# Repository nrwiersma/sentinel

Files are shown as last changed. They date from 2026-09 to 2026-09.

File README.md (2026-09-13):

<picture>
  <source media="(prefers-color-scheme: dark)" srcset="http://svg.wiersma.co.za/github/project.v2?title=sentinel&tag=presence%20detection&mode=dark">
  <source media="(prefers-color-scheme: light)" srcset="http://svg.wiersma.co.za/github/project.v2?title=sentinel&tag=presence%20detection">
  sentinel&tag=presence%20detection"
</picture>




`Sentinal` is a presence detection device that uses a mmWave to detect occupancy. It can be used to control lights, fans, 
or other devices based on occupancy. It also include a light sensor to detect ambient light levels as well as a temperature 
and humidity sensor.

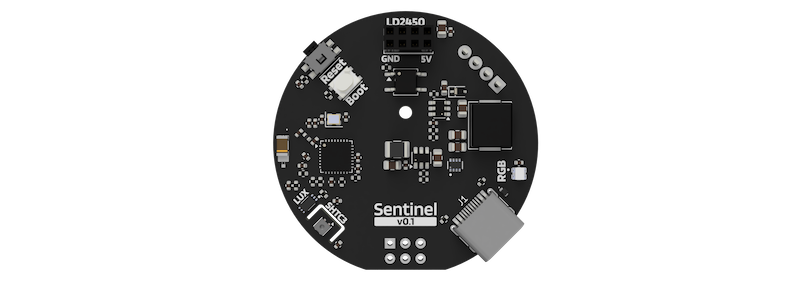
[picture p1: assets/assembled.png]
board image


## Key Features

* Presence detection using LD2450 mmWave radar
* Ambient light detection using BH1750 light sensor
* Temperature and humidity detection using SHTC3 sensor
* RGB LED for status indication
* Native alarm integration

## Firmware

ESPHome firmware is available for the device. See the releases for the latest version. The firmware can be flashed 
using the [ESPHome Web installer](https://web.esphome.io).

## Hardware

The hardware is based on the ESP32-C3 module and the LD2450 mmWave radar module. The device is designed to be low power 
and can be powered using a 12v power supply, which is fairly common in home alarm systems.

See the [Schematic](/blob/main/hardware/schematic.pdf) for more details on the hardware design.

### BOM

See the [Interactive BOM](https://htmlpreview.github.io/?https://github.com/nrwiersma/sentinel/blob/main/bom/ibom.html) [(provided by InteractiveHtmlBom)
](https://github.com/openscopeproject/InteractiveHtmlBom).

### Update LD2450 Firmware

* Download the HLKRadarTool on your phone
* Connect to the LD2450 module via Bluetooth
* Update the firmware to version 2.04.23101915 or later

> [!WARNING]
> If upgrading the firmware version to 2.14 or later, you need to set the baud rate back to 256000 in the HLKRadarTool 
> app. This version change seems to reset the baud rate, and Sentinel will no longer be able to communicate with the LD2450 module.

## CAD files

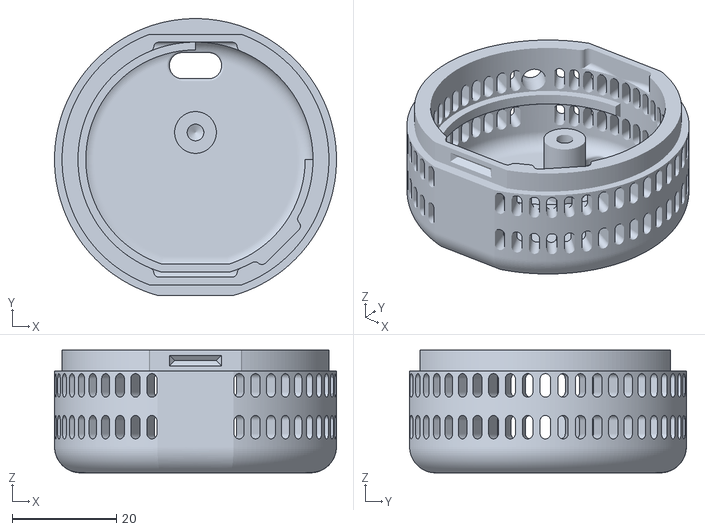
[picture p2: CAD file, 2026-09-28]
models/Base.stl
54.0 x 53.0 x 23.5

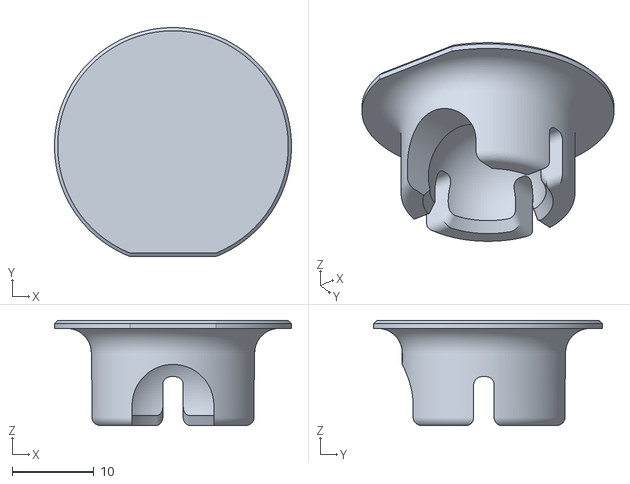
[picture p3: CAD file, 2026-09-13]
models/Ball Socket.stl
29.0 x 28.0 x 12.9

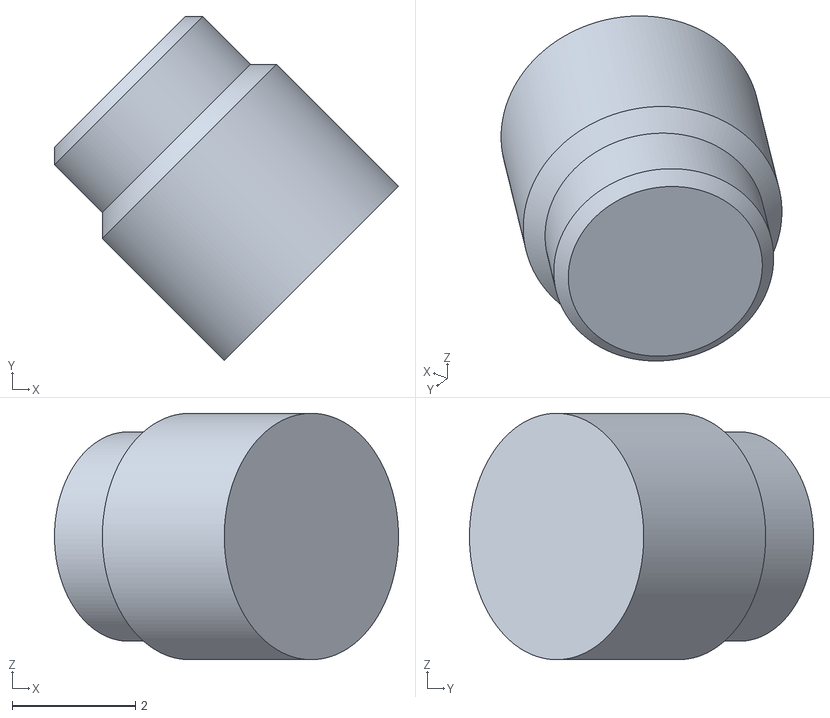
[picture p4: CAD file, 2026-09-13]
models/Button.stl
5.59 x 5.59 x 4.00

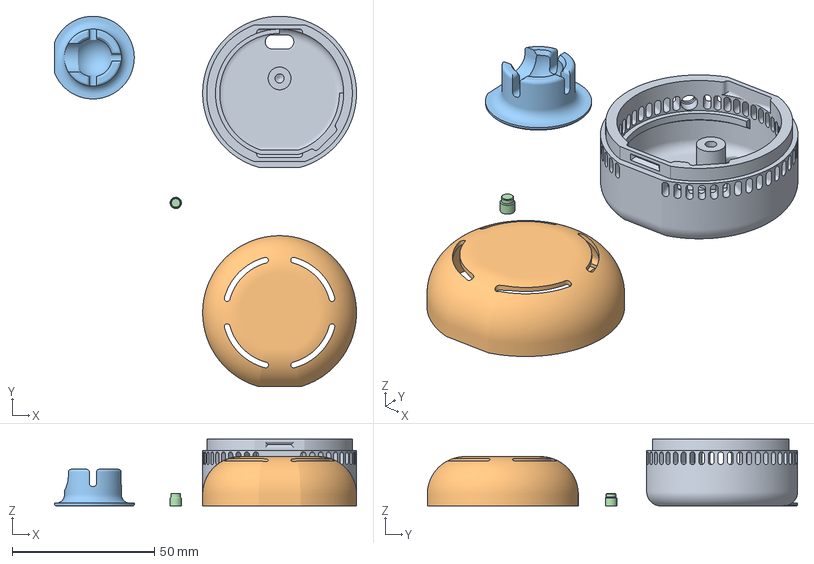
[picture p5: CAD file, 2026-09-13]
models/Sentinel.3mf
106.0 x 130.0 x 23.5 mm
Base.stl
Lid.stl
Ball Socket.stl
Button.stl

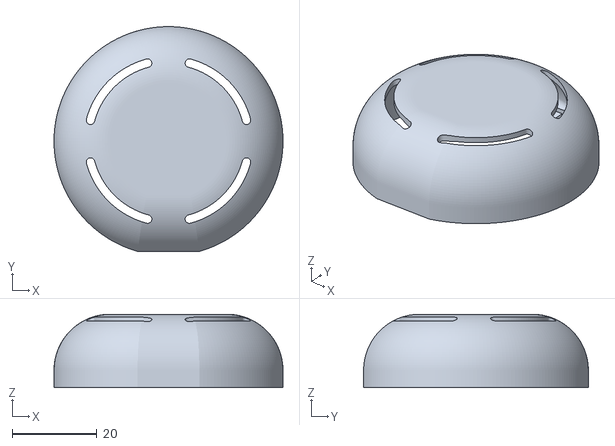
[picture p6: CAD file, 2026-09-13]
models/Lid.stl
54.0 x 53.0 x 17.3

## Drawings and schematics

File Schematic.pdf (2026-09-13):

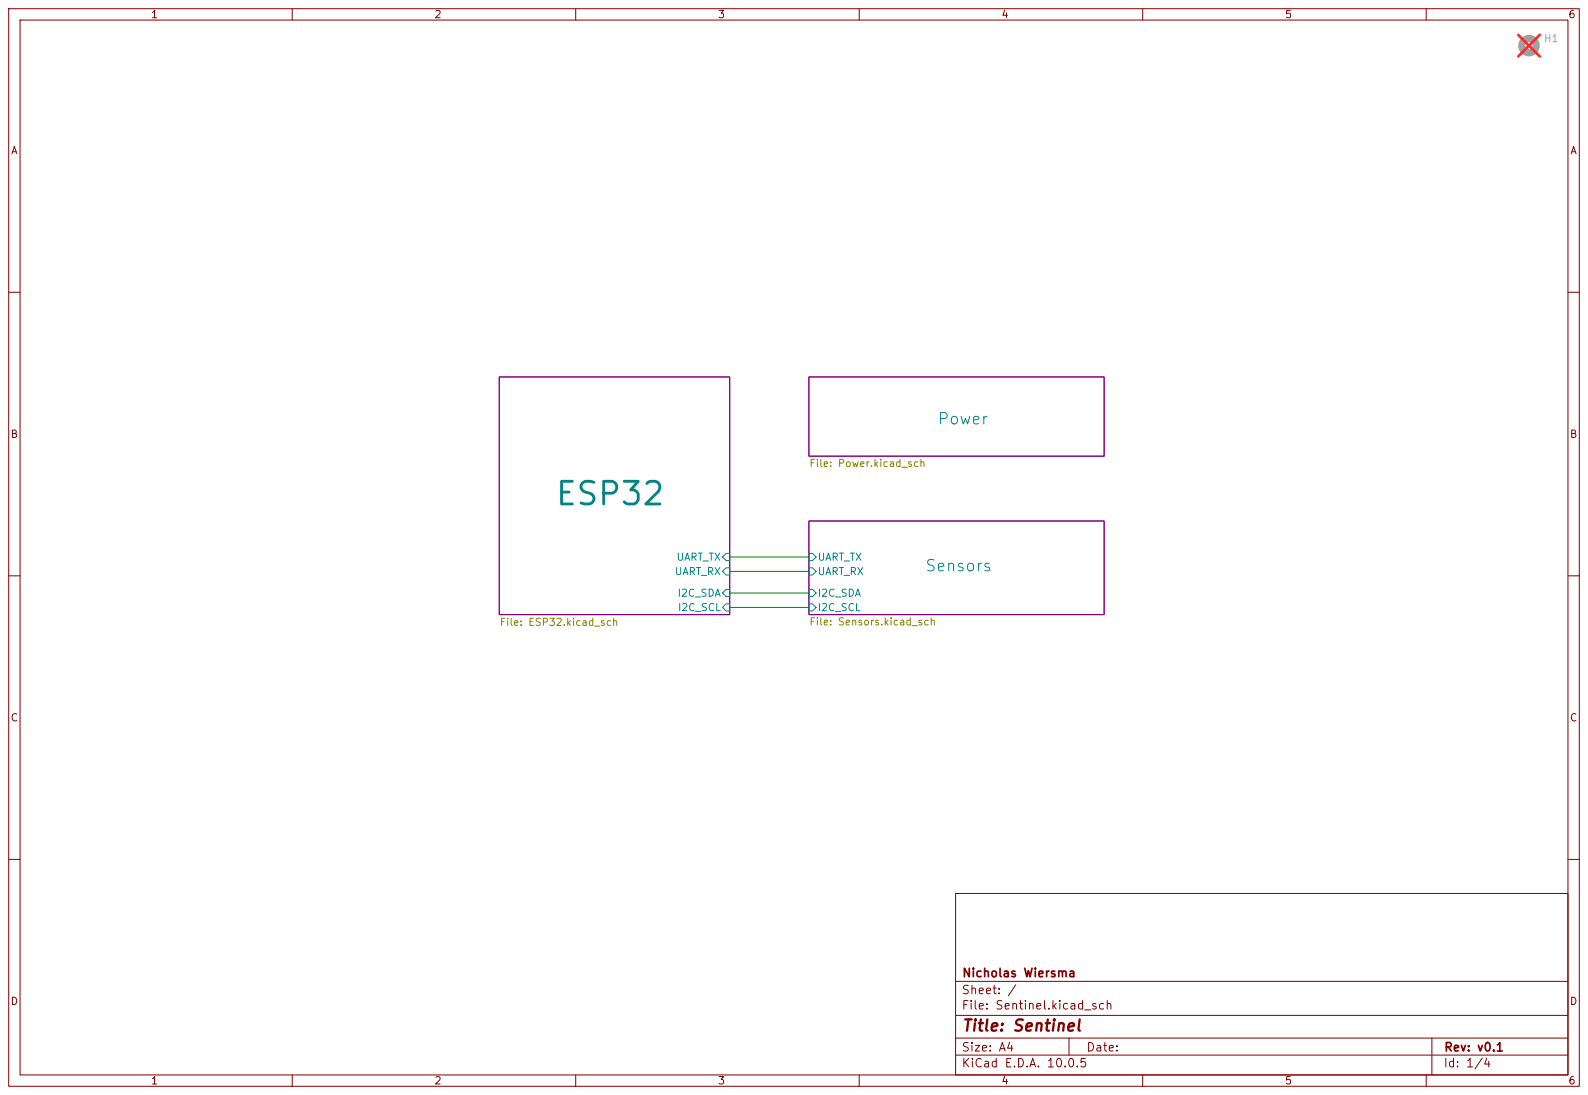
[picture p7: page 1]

Size: A4 | Rev: v0.1
KiCad E.D.A. 10.0.5 | Id: 1/4

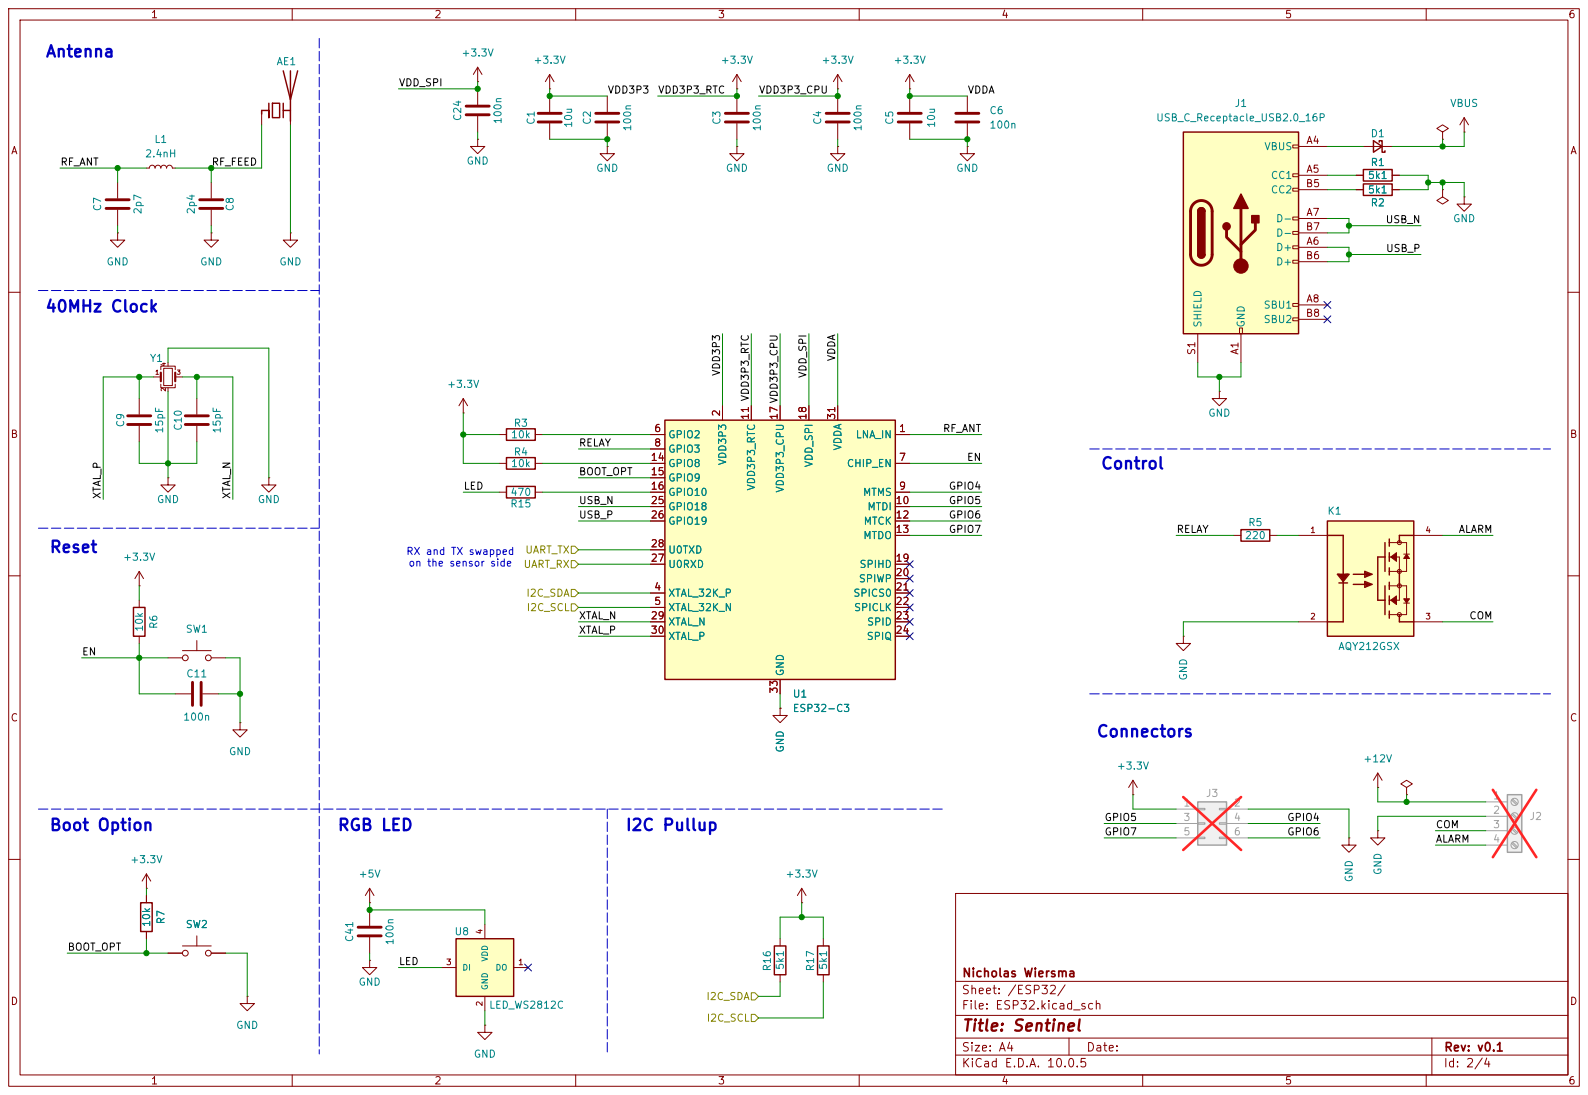
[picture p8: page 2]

on the sensor side 40MHz Clock

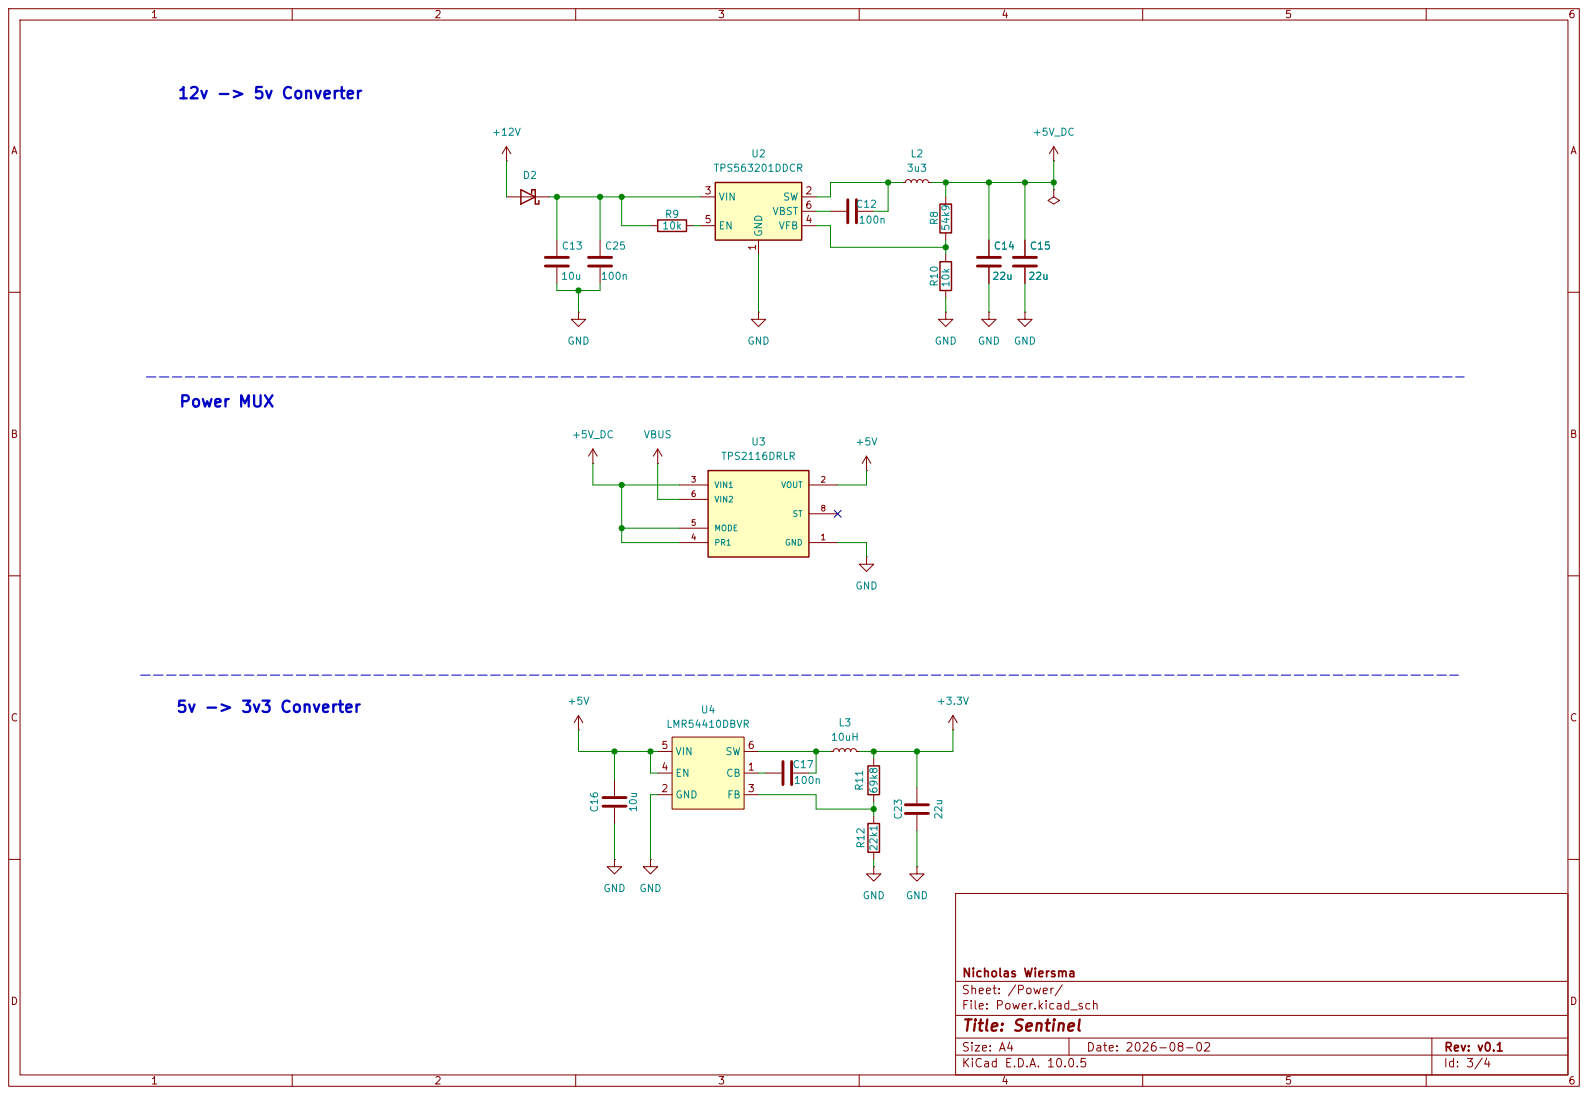
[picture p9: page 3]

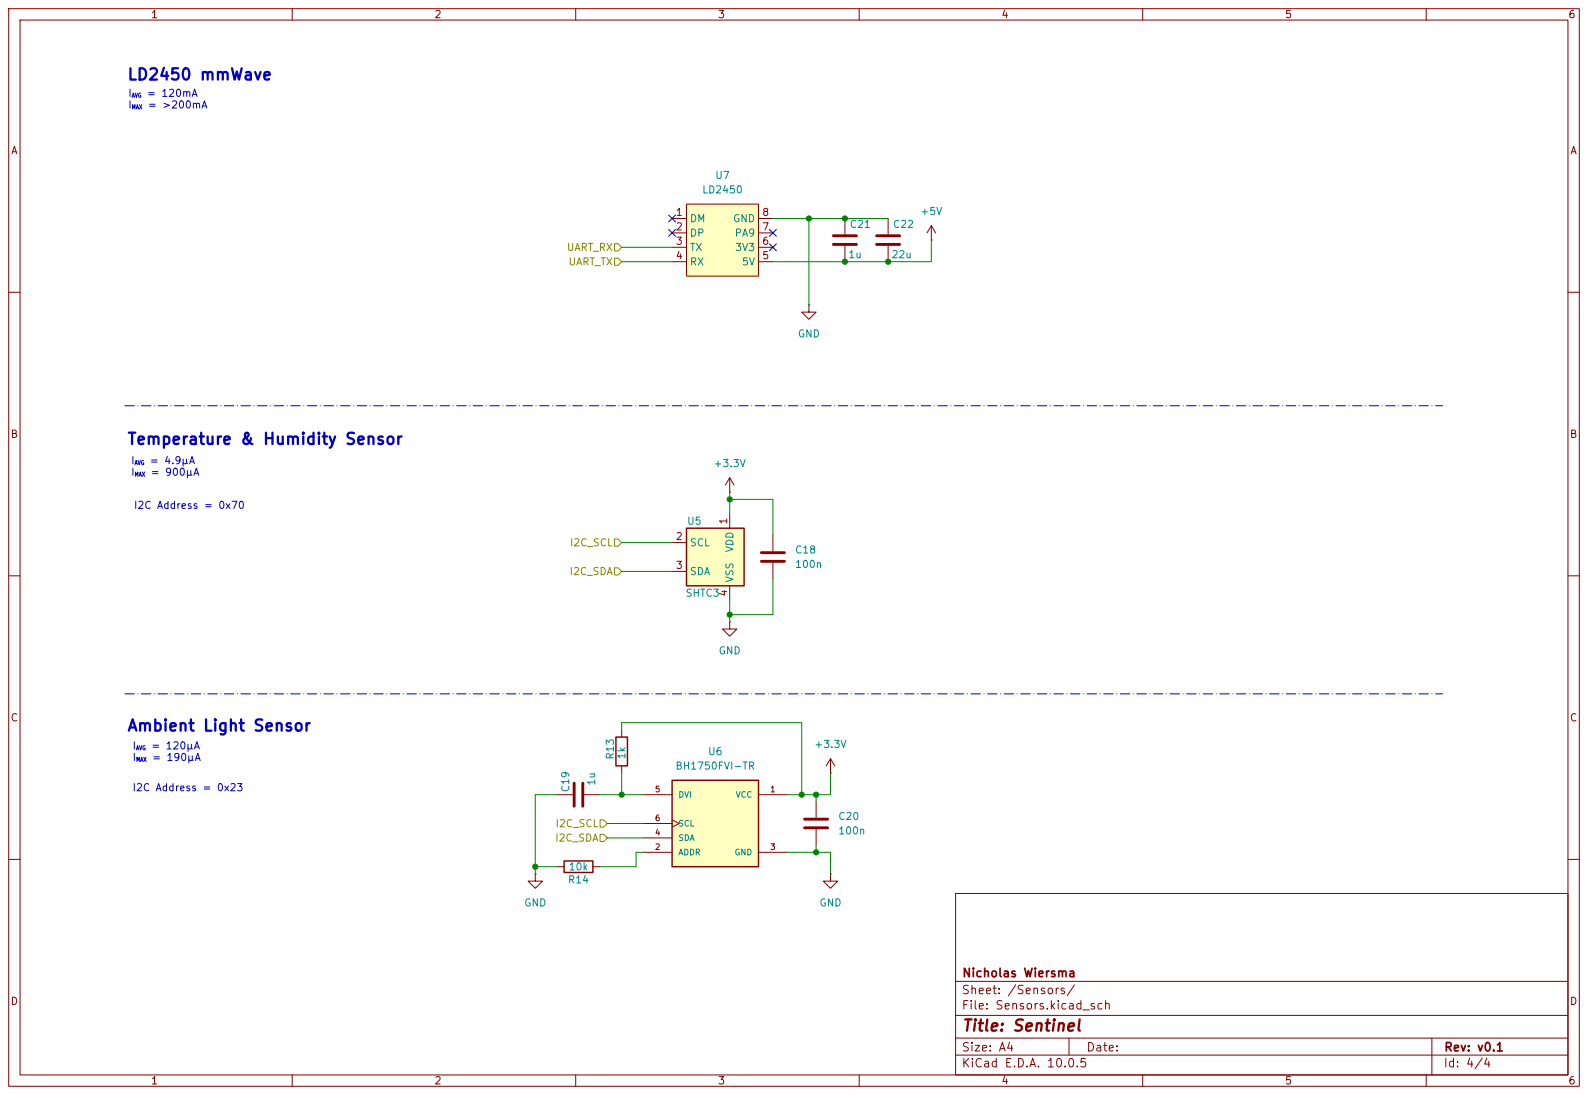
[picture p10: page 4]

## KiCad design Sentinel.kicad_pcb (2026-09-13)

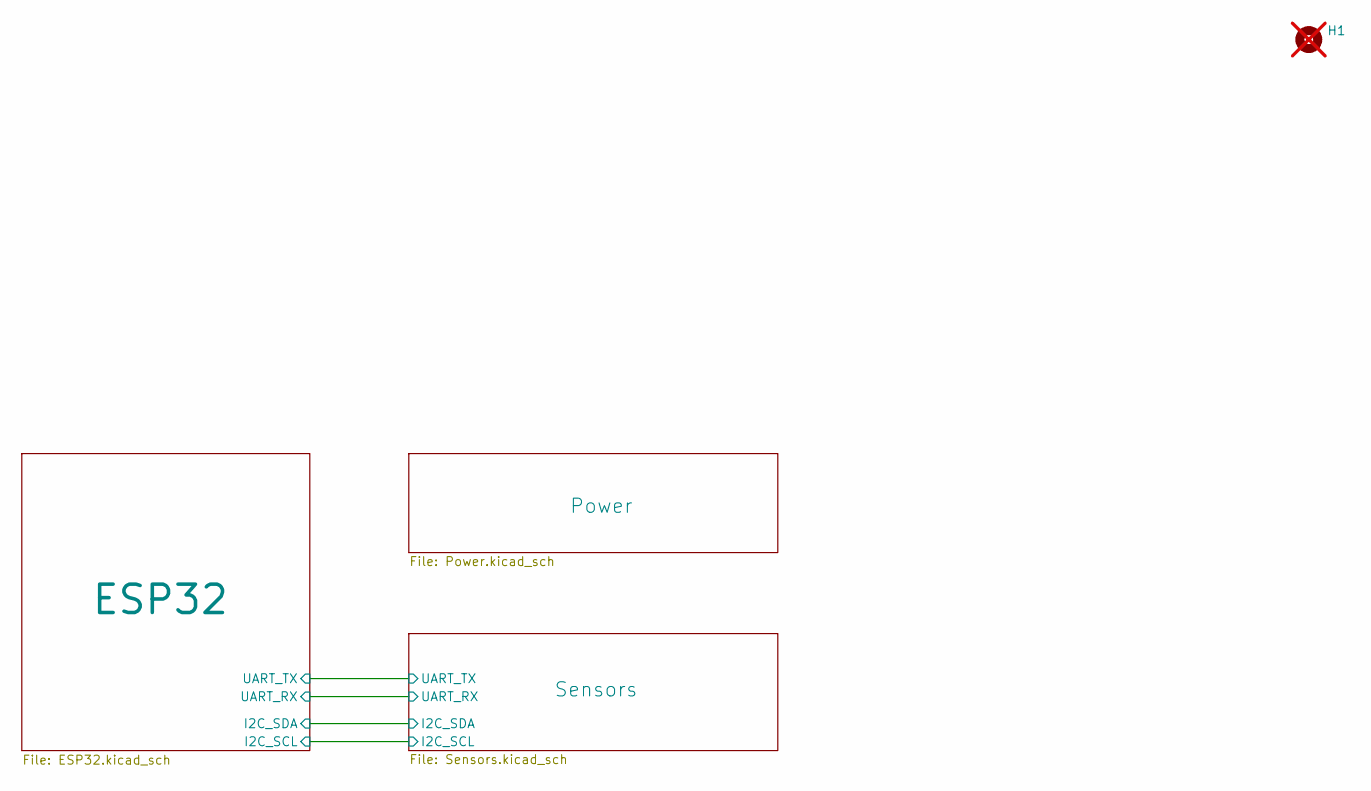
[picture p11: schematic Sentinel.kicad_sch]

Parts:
H1: MountingHole; MountingHole_2.2mm_M2; not fitted

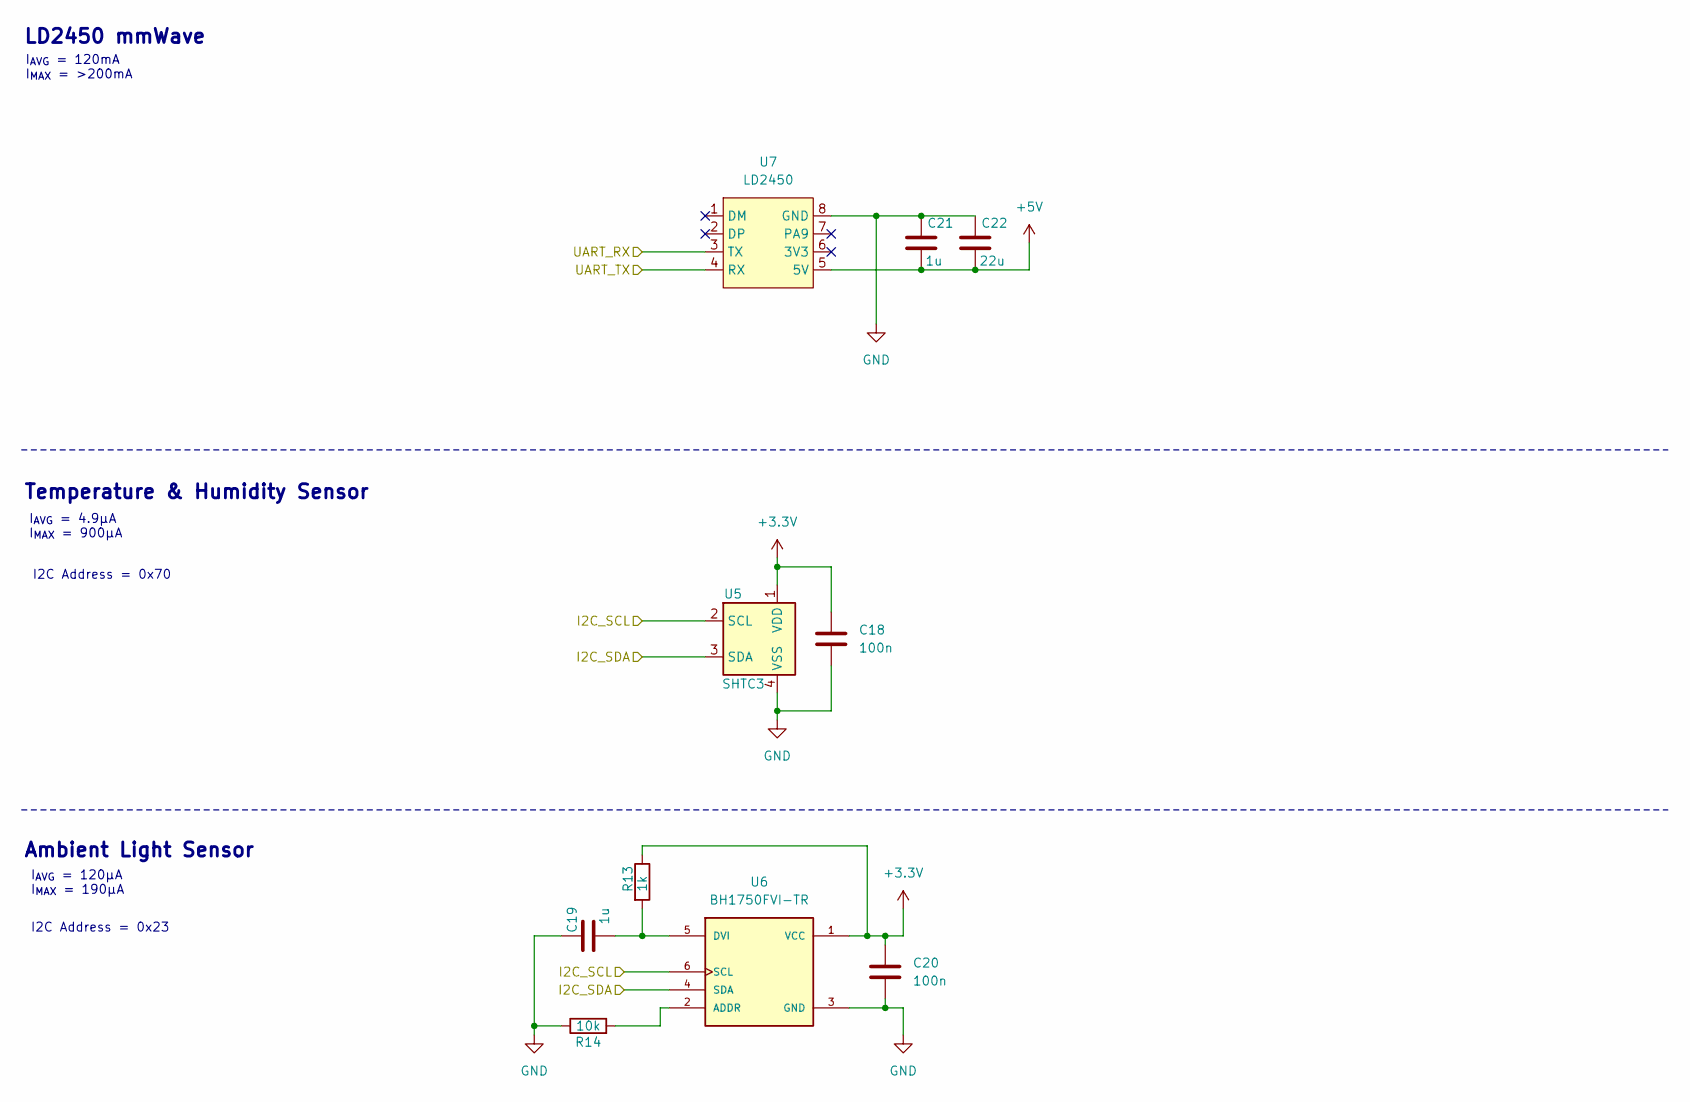
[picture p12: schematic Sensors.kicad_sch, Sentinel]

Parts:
C18, C20: 100n; C_0402_1005Metric; MPN CL05B104KO5NNNC; JLCPCB Part # C1525
C19, C21: 1u; C_0402_1005Metric; MPN CL05A105KP5NNNC; JLCPCB Part # C14445
C22: 22u; C_0805_2012Metric; MPN CL21A226KPCLRNC; JLCPCB Part # C318688
R13: 1k; R_0402_1005Metric; MPN RK73H1ETTP1001F; JLCPCB Part # C131360
R14: 10k; R_0402_1005Metric; MPN RC0402FR-0710KL; JLCPCB Part # C60490
U5: SHTC3; SHTC3-TR; MPN SHTC3-TR-10KS; JLCPCB Part # C2880044
U6: BH1750FVI-TR; MPN BH1750FVI-TR; JLCPCB Part # C78960
U7: LD2450; MPN 2005FV-2x4P; JLCPCB Part # C18723066

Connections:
+3.3V: C18.1, C20.1, R13.1, U5.1 (VDD), U6.1 (VCC); also elsewhere on the board
+5V: C21.2, C22.2, U7.5 (5V); also elsewhere on the board
/ESP32/I2C_SCL: U5.2 (SCL), U6.6 (SCL); also elsewhere on the board
/ESP32/I2C_SDA: U5.3 (SDA), U6.4 (SDA); also elsewhere on the board
/ESP32/UART_RX: U7.3 (TX); also elsewhere on the board
/ESP32/UART_TX: U7.4 (RX); also elsewhere on the board
GND: C18.2, C19.1, C20.2, C21.1, C22.1, R14.1, U5.4 (VSS), U6.3 (GND), U7.8 (GND); also elsewhere on the board
unnamed: R14.2, U6.2 (ADDR)
unnamed: C19.2, R13.2, U6.5 (DVI)

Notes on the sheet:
I2C Address = 0x70
I_{AVG} = 120μA I_{MAX} = 190μA
I_{AVG} = 120mA I_{MAX} = >200mA
I_{AVG} = 4.9μA I_{MAX} = 900μA
Ambient Light Sensor
LD2450 mmWave
Temperature & Humidity Sensor
I2C Address = 0x23

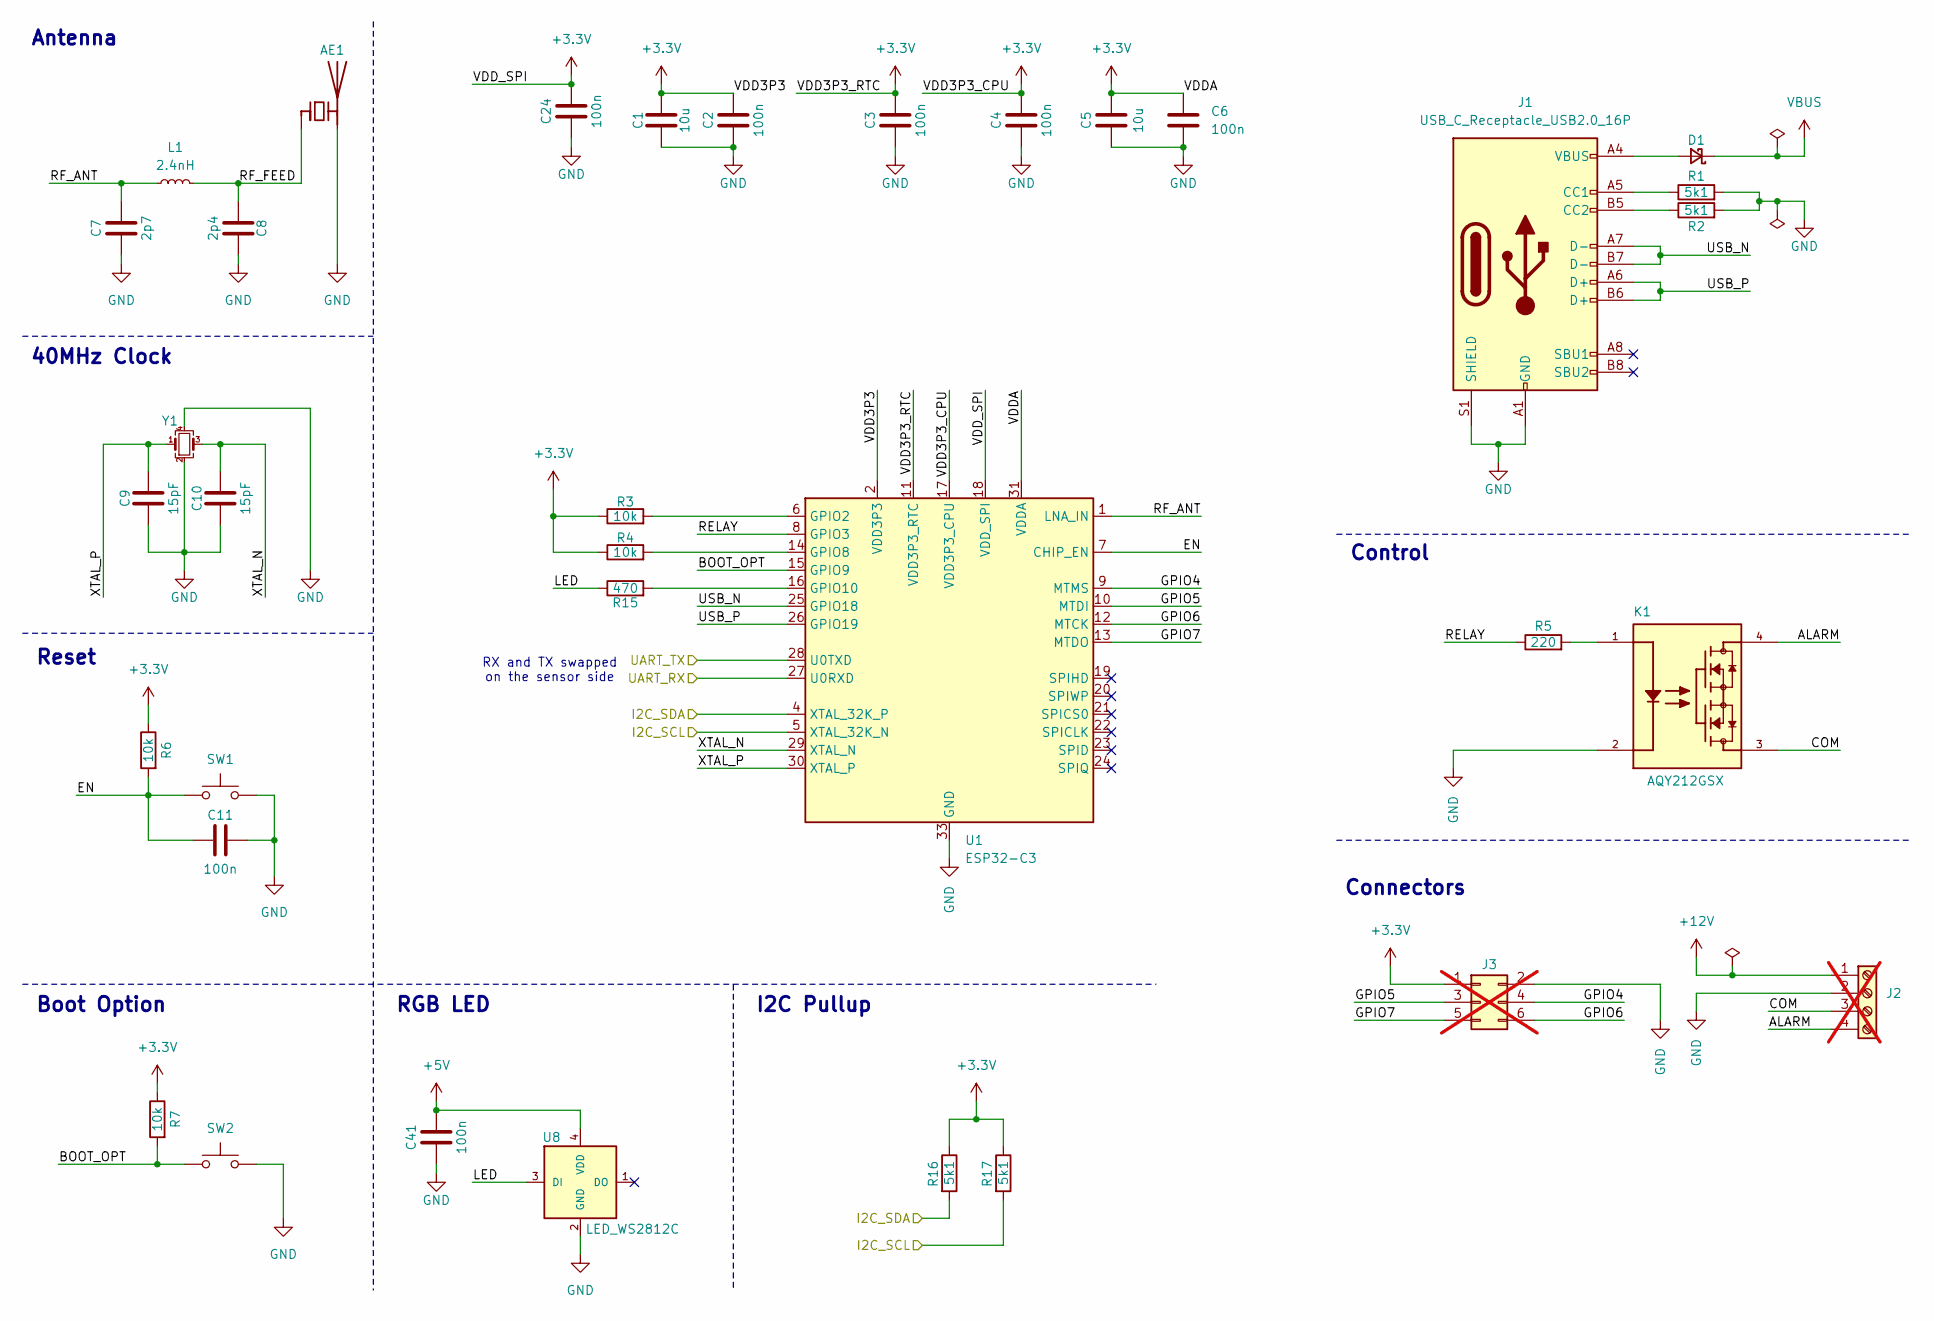
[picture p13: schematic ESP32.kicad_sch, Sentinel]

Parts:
AE1: Ant_RFECA3216060A1T_1206; Ant_RFECA3216060A1T; MPN RFECA3216060A1T; JLCPCB Part # C127620
C1, C5: 10u; C_0402_1005Metric; MPN CL05A106MP5NUNC; JLCPCB Part # C315248
C2, C3, C4, C6, C11, C24, C41: 100n; C_0402_1005Metric; MPN CL05B104KO5NNNC; JLCPCB Part # C1525
C7: 2p7; C_0402_1005Metric; MPN CL05C2R7BB5NNNC; JLCPCB Part # C159805
C8: 2p4; C_0402_1005Metric; MPN CL05C2R4CB5NNNC; JLCPCB Part # C318575
C9, C10: 15pF; C_0402_1005Metric; MPN CL05C150JB5NNNC; JLCPCB Part # C86285
D1: D_Schottky_Small; D_0402_1005Metric; MPN CDBQC0130L-HF; JLCPCB Part # C2886012
J1: USB_C_Receptacle_USB2.0_16P; USB_C_Receptacle_HRO_TYPE-C-31-M-12; MPN TYPE-C-31-M-12; JLCPCB Part # C165948
J2: Screw_Terminal_01x04; TerminalBlock_Phoenix_MPT-0,5-4-2.54_1x04_P2.54mm_Horizontal; not fitted
J3: Conn_02x03_Odd_Even; PinHeader_2x03_P2.54mm_Vertical; not fitted
K1: AQY212GSX; SSR_SUPSiC_GAQY212GSX; MPN GAQY212GSX; JLCPCB Part # C19271988
L1: 2.4nH; L_0402_1005Metric; MPN MLG1005S2N4BT000; JLCPCB Part # C275281
R1, R2, R16, R17: 5k1; R_0402_1005Metric; MPN RC0402FR-075K1L; JLCPCB Part # C105872
R3, R4, R6, R7: 10k; R_0402_1005Metric; MPN RC0402FR-0710KL; JLCPCB Part # C60490
R5: 220; R_0402_1005Metric; MPN RC0402FR-07220RL; JLCPCB Part # C112291
R15: 470; R_0402_1005Metric; MPN RC0402FR-7W470RL; JLCPCB Part # C606172
SW1: SW_Push; SW_Panasonic_EVQPUC; MPN EVQPUC02K; JLCPCB Part # C79174
SW2: SW_Push; SW_PTS815SJM250SMTRLFS; MPN SKRPACE010; JLCPCB Part # C139797
U1: ESP32-C3; QFN-32-1EP; MPN ESP32-C3FH4; JLCPCB Part # C2858491
U8: LED_WS2812C; LED_WS2812C-2020; MPN WS2812C-2020; JLCPCB Part # C2976072
Y1: ECS-400-10-37B2-CKM-TR; Oscillator_ECS_400-10-37B2-CKM-TR; MPN ECS-400-10-37B2-CKM-TR; JLCPCB Part # C5371760

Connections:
+3.3V: C1.1, C2.1, C3.1, C4.1, C5.1, C6.1, C24.1, J3.1, R3.1, R4.1, R6.1, R7.1, R16.1, R17.1, U1.2 (VDD3P3), U1.3 (VDD3P3), U1.11 (VDD3P3_RTC), U1.17 (VDD3P3_CPU), U1.18 (VDD_SPI), U1.31 (VDDA), U1.32 (VDDA); also elsewhere on the board
+5V: C41.1, U8.4 (VDD); also elsewhere on the board
+12V: J2.1; also elsewhere on the board
/ESP32/ALARM: J2.4, K1.4
/ESP32/BOOT_OPT: R7.2, SW2.2, U1.15 (GPIO9)
/ESP32/COM: J2.3, K1.3
/ESP32/EN: C11.1, R6.2, SW1.2, U1.7 (CHIP_EN)
/ESP32/GPIO4: J3.4, U1.9 (MTMS)
/ESP32/GPIO5: J3.3, U1.10 (MTDI)
/ESP32/GPIO6: J3.6, U1.12 (MTCK)
/ESP32/GPIO7: J3.5, U1.13 (MTDO)
/ESP32/I2C_SCL: R17.2, U1.5 (XTAL_32K_N); also elsewhere on the board
/ESP32/I2C_SDA: R16.2, U1.4 (XTAL_32K_P); also elsewhere on the board
/ESP32/LED: R15.1, U8.3 (DI)
/ESP32/RELAY: R5.1, U1.8 (GPIO3)
/ESP32/RF_ANT: C7.1, L1.1, U1.1 (LNA_IN)
/ESP32/RF_FEED: AE1.1 (FEED), C8.2, L1.2
/ESP32/UART_RX: U1.27 (U0RXD); also elsewhere on the board
/ESP32/UART_TX: U1.28 (U0TXD); also elsewhere on the board
/ESP32/USB_N: J1.A7 (D-), J1.B7 (D-), U1.25 (GPIO18)
/ESP32/USB_P: J1.A6 (D+), J1.B6 (D+), U1.26 (GPIO19)
/ESP32/XTAL_N: C10.1, U1.29 (XTAL_N), Y1.3
/ESP32/XTAL_P: C9.1, U1.30 (XTAL_P), Y1.1
GND: AE1.2 (PCB_Trace), C1.2, C2.2, C3.2, C4.2, C5.2, C6.2, C7.2, C8.1, C9.2, C10.2, C11.2, C24.2, C41.2, J1.A1 (GND), J1.A12 (GND), J1.B1 (GND), J1.B12 (GND), J1.S1 (SHIELD), J2.2, J3.2, K1.2, R1.2, R2.2, SW1.1, SW2.1, U1.33 (GND), U8.2 (GND), Y1.2, Y1.4; also elsewhere on the board
unnamed: D1.2 (A), J1.A4 (VBUS), J1.A9 (VBUS), J1.B4 (VBUS), J1.B9 (VBUS)
unnamed: J1.A5 (CC1), R1.1
unnamed: J1.B5 (CC2), R2.1
unnamed: K1.1, R5.2
unnamed: R3.2, U1.6 (GPIO2)
unnamed: R4.2, U1.14 (GPIO8)
unnamed: R15.2, U1.16 (GPIO10)
VBUS: D1.1 (K); also elsewhere on the board

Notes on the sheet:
Boot Option
RGB LED
Antenna
Connectors
I2C Pullup
RX and TX swapped on the sensor side
40MHz Clock
Control
Reset

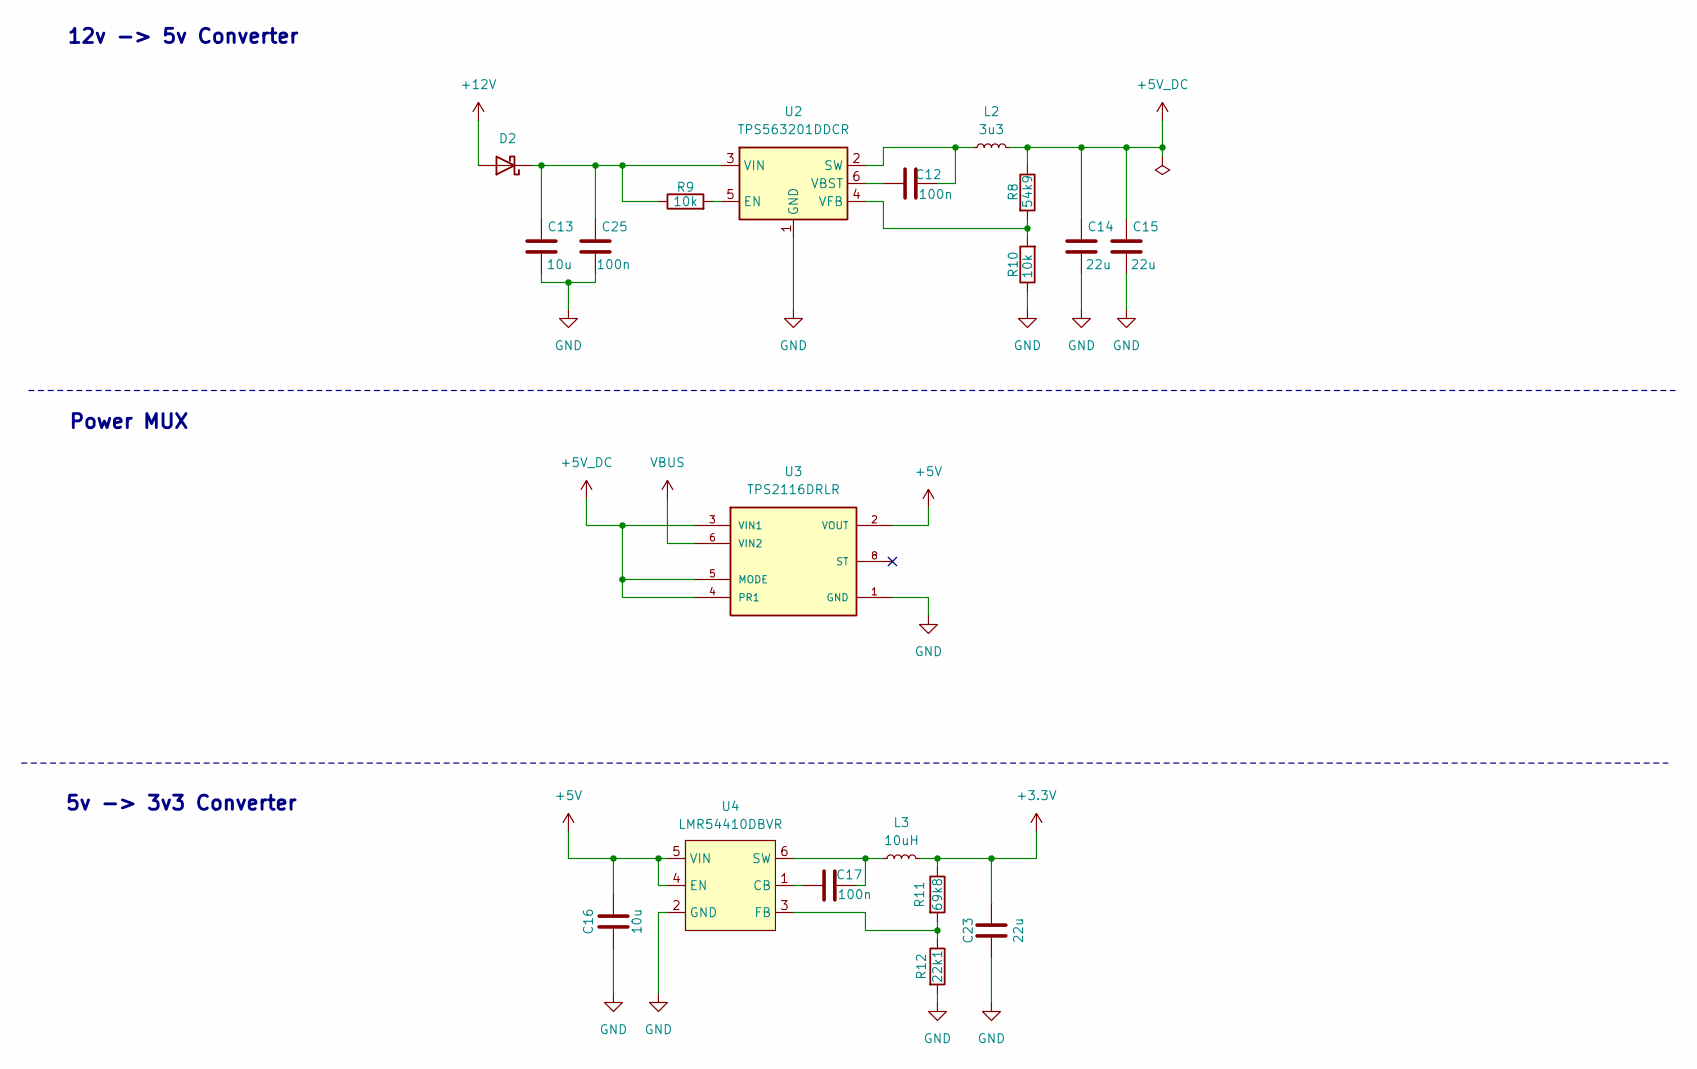
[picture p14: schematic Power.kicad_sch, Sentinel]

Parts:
C12, C17: 100n; C_0402_1005Metric; MPN CL05B104KO5NNNC; JLCPCB Part # C1525
C13, C16: 10u; C_0805_2012Metric; MPN CL21A106KAYNNNE; JLCPCB Part # C15850
C14, C15, C23: 22u; C_0805_2012Metric; MPN CL21A226KPCLRNC; JLCPCB Part # C318688
C25: 100n; C_0603_1608Metric; MPN CL10B104KA8NNNC; JLCPCB Part # C1590
D2: 1N5819WS; D_SOD-323; MPN 1N5819WS; JLCPCB Part # C191023
L2: 3u3; L_Chilisin_BMRx00060630; MPN MHCI06030-3R3M-S8; JLCPCB Part # C285713
L3: 10uH; L_1210_3225Metric; MPN TMS322512ALM-100MTAA; JLCPCB Part # C20244098
R8: 54k9; R_0402_1005Metric; MPN AC0402FR-0754K9L; JLCPCB Part # C227137
R9, R10: 10k; R_0402_1005Metric; MPN RC0402FR-0710KL; JLCPCB Part # C60490
R11: 69k8; R_0402_1005Metric; MPN AC0402FR-0769K8L; JLCPCB Part # C227195
R12: 22k1; R_0402_1005Metric; MPN RC0402FR-0722K1L; JLCPCB Part # C163478
U2: TPS563201DDCR; SOT-23-6; MPN TPS563201DDCR; JLCPCB Part # C116592
U3: TPS2116DRLR; SOTFL50P160X60-8N; MPN TPS2116DRLR; JLCPCB Part # C3235557
U4: LMR54410DBVR; SOT-23-6; MPN LMR54410DBVR; JLCPCB Part # C3200265

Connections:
+3.3V: C23.2, L3.2, R11.1; also elsewhere on the board
+5V: C16.2, U3.2 (VOUT), U3.7 (VOUT), U4.4 (EN), U4.5 (VIN); also elsewhere on the board
+5V_DC: C14.1, C15.1, L2.2, R8.1, U3.3 (VIN1), U3.4 (PR1), U3.5 (MODE)
+12V: D2.2 (A); also elsewhere on the board
GND: C13.2, C14.2, C15.2, C16.1, C23.1, C25.2, R10.1, R12.2, U2.1 (GND), U3.1 (GND), U4.2 (GND); also elsewhere on the board
unnamed: C13.1, C25.1, D2.1 (K), R9.1, U2.3 (VIN)
unnamed: R9.2, U2.5 (EN)
unnamed: C12.2, L2.1, U2.2 (SW)
unnamed: C12.1, U2.6 (VBST)
unnamed: R8.2, R10.2, U2.4 (VFB)
unnamed: C17.1, U4.1 (CB)
unnamed: R11.2, R12.1, U4.3 (FB)
unnamed: C17.2, L3.1, U4.6 (SW)
VBUS: U3.6 (VIN2); also elsewhere on the board

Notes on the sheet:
5v -> 3v3 Converter
Power MUX
12v -> 5v Converter

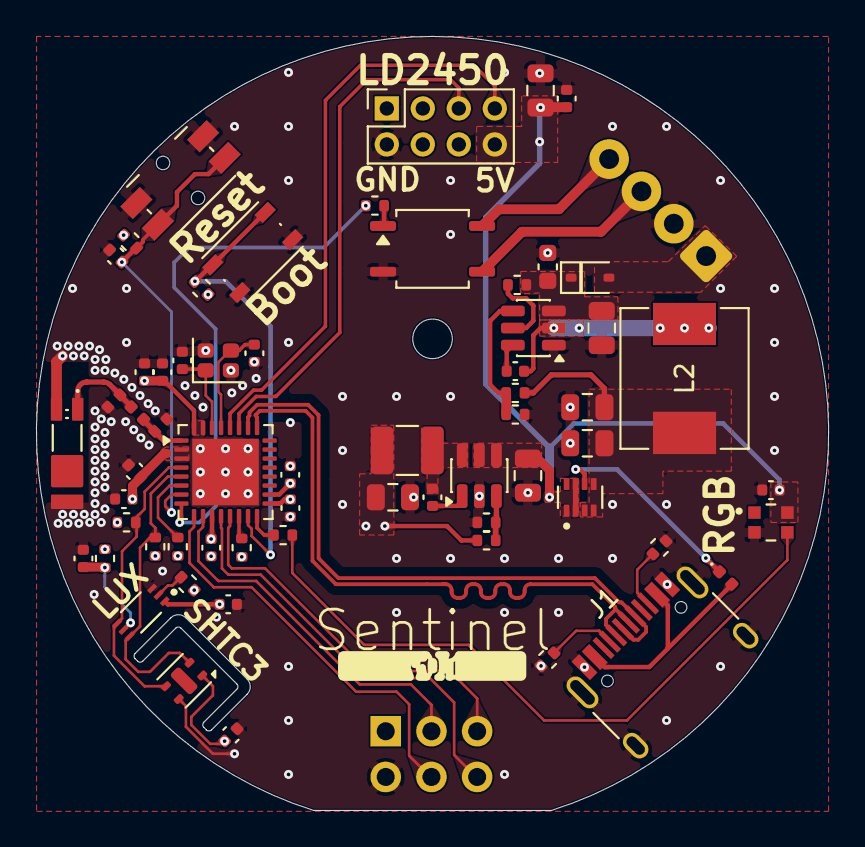
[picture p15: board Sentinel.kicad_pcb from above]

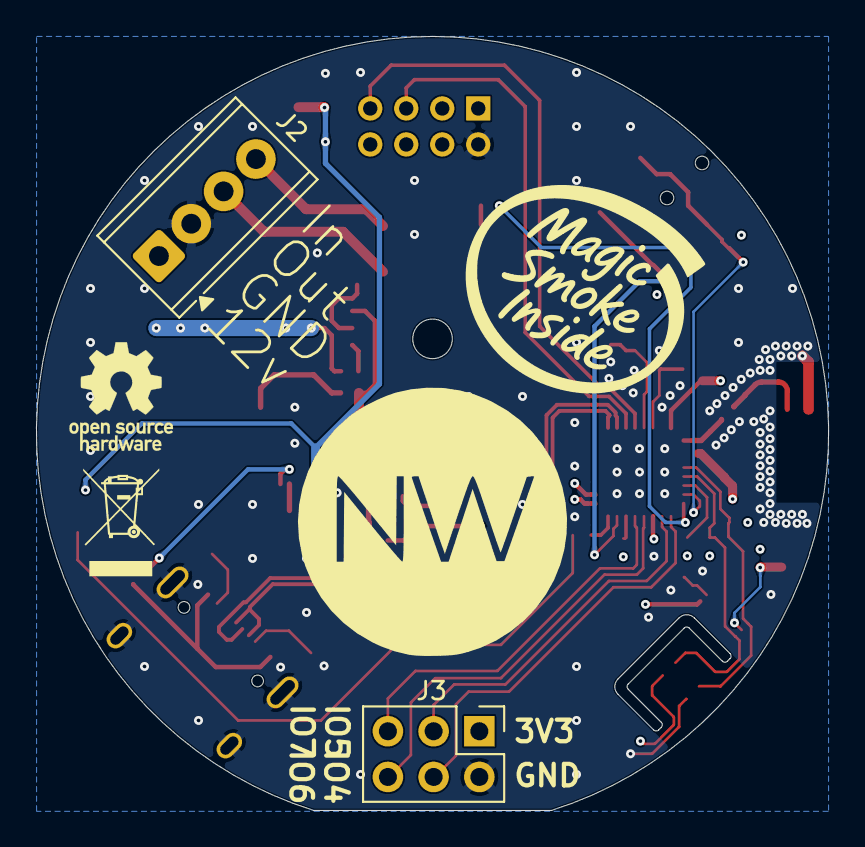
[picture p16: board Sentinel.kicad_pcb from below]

Board: 4 copper layers, 44.0 x 43.0 mm, 65 parts (2 on the bottom side), 43 nets.

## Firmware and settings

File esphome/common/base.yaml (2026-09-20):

esphome:
  project:
    name: nrwiersma.Sentinel
    version: "0.1.0"
  on_boot:
    - priority: 375
      then:
        - delay: 200ms
        - script.execute: update_relay_state
        # Start loading animation and keep it until API connects
        - if:
            condition:
              lambda: 'return id(status_led_select).current_option() == "Enabled";'
            then:
              - light.turn_on:
                  id: led_rgb
                  brightness: 30%
                  red: 0%
                  green: 60%
                  blue: 100%
                  white: 0%
                  effect: "Network Connecting"

logger:
  level: ${log_level}

api:
  id: api_id
  on_client_connected:
    then:
      # Wait until client has subscribed
      - wait_until:
          condition:
            api.connected:
              state_subscription_only: true
          timeout: 3s
      - if:
          condition:
            lambda: 'return id(status_led_select).current_option() == "Enabled" && id(led_mode_select).current_option() != "Manual Control";'
          then:
            # Stop any effects first
            - light.turn_on:
                id: led_rgb
                effect: none
            # Smooth celebration sequence with flowing colors
            - light.turn_on:
                id: led_rgb
                brightness: 60%
                red: 0%
                green: 100%
                blue: 100%
                white: 0%
                transition_length: 400ms
            - delay: 400ms
            - light.turn_on:
                id: led_rgb
                brightness: 65%
                red: 0%
                green: 70%
                blue: 100%
                white: 0%
                transition_length: 350ms
            - delay: 350ms
            - light.turn_on:
                id: led_rgb
                brightness: 70%
                red: 50%
                green: 0%
                blue: 100%
                white: 0%
                transition_length: 350ms
            - delay: 350ms
            - light.turn_on:
                id: led_rgb
                brightness: 65%
                red: 100%
                green: 100%
                blue: 100%
                white: 0%
                transition_length: 400ms
            - delay: 500ms
      # Always restore to current mode, even if Manual Control
      - script.execute: control_leds

  on_client_disconnected:
    then:
      - script.execute: control_leds

http_request:
  verify_ssl: false

ota:
  - platform: esphome
  - platform: http_request
    id: ota_http_request

sensor:
  - platform: shtcx
    id: "shtc3_sensor"
    i2c_id: bus_a
    address: 0x70
    update_interval: 30s
    temperature:
      name: Temperature
      id: temperature_sensor
      filters:
        - lambda: "return x + id(env_temperature_offset).state;"
    humidity:
      name: Humidity
      id: humidity_sensor
      filters:
        - lambda: "return x + id(env_humidity_offset).state;"

  - platform: bh1750
    name: Illuminance
    id: illuminance_sensor
    i2c_id: bus_a
    address: 0x23
    update_interval: 2s
    filters:
      - lambda: "return x + id(env_illuminance_offset).state;"
      - or:
          - throttle: 30s
          - delta: 2
      - clamp:
          min_value: 0

i2c:
  - id: bus_a
    scl: GPIO1
    sda: GPIO0
    scan: true

binary_sensor:
  - platform: template
    name: Occupancy
    id: occupancy
    device_class: occupancy
    filters:
      - delayed_off: !lambda 'return id(occupancy_off_delay).state * 1000.0;'
    lambda: |-
      return id(ld2450_occupancy).state;
    on_state:
      then:
        - lambda: |-
            auto mode = id(system_alarm_mode).current_option();
            if (mode == "Presence") {
              bool activate = id(occupancy).state;
              bool desired = (id(relay_contact_mode).current_option() == "Normally Open (NO)") ? activate : !activate;
              if (desired) {
                id(system_alarm_relay).turn_on();
              } else {
                id(system_alarm_relay).turn_off();
              }
            }
        - if:
            condition:
              lambda: |-
                return id(led_mode_select).current_option() == "Presence";
            then:
              - script.execute: control_leds
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

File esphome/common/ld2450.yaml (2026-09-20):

uart:
  id: uart_bus
  tx_pin: GPIO21
  rx_pin: GPIO20
  baud_rate: 256000
  parity: NONE
  stop_bits: 1

ld2450:
  id: ld2450_radar
  uart_id: uart_bus
  on_data:
    - lambda: |-
        struct Poly { float vx[20]; float vy[20]; int count; };
        static Poly zones[4], exclusions[2];

        if (!id(poly_initialized)) {
          auto parse = [](const std::string &text, Poly &poly) {
            poly.count = 0;
            size_t pos = 0;
            while (pos < text.length() && poly.count < 20) {
              int x, y, n;
              if (sscanf(text.c_str() + pos, "%d:%d%n", &x, &y, &n) == 2) {
                poly.vx[poly.count] = (float)x;
                poly.vy[poly.count] = (float)y;
                poly.count++;
                pos += n;
                if (pos < text.length() && text[pos] == ';') pos++;
              } else {
                break;
              }
            }
          };
          parse(id(poly_zone_1).state, zones[0]);
          parse(id(poly_zone_2).state, zones[1]);
          parse(id(poly_zone_3).state, zones[2]);
          parse(id(poly_zone_4).state, zones[3]);
          parse(id(poly_exclusion_1).state, exclusions[0]);
          parse(id(poly_exclusion_2).state, exclusions[1]);
          id(poly_initialized) = true;
        }

        auto in_poly = [](float px, float py, const Poly &poly) -> bool {
          if (poly.count < 3) return false;
          bool inside = false;
          for (int i = 0, j = poly.count - 1; i < poly.count; j = i++) {
            float xi = poly.vx[i], yi = poly.vy[i];
            float xj = poly.vx[j], yj = poly.vy[j];
            if (((yi > py) != (yj > py)) &&
                (px < (xj - xi) * (py - yi) / (yj - yi) + xi)) {
              inside = !inside;
            }
          }
          return inside;
        };

        int detail = id(extra_entities);  // 0=Targets Position .. 4=Speed and Resolution (see select below)

        decltype(id(target1_x)) pos_x[] = {id(target1_x), id(target2_x), id(target3_x)};
        decltype(id(target1_y)) pos_y[] = {id(target1_y), id(target2_y), id(target3_y)};
        decltype(id(target1_active)) actives[] = {id(target1_active), id(target2_active), id(target3_active)};
        decltype(id(target1_distance)) distances[] = {id(target1_distance), id(target2_distance), id(target3_distance)};
        decltype(id(target1_angle)) angles[] = {id(target1_angle), id(target2_angle), id(target3_angle)};
        decltype(id(target1_speed)) speeds[] = {id(target1_speed), id(target2_speed), id(target3_speed)};
        decltype(id(target1_resolution)) resolutions[] = {id(target1_resolution), id(target2_resolution), id(target3_resolution)};

        decltype(id(zone1_target_count)) zone_counts[] = {id(zone1_target_count), id(zone2_target_count), id(zone3_target_count), id(zone4_target_count)};
        decltype(id(zone1_occupancy)) zone_presence[] = {id(zone1_occupancy), id(zone2_occupancy), id(zone3_occupancy), id(zone4_occupancy)};
        decltype(id(mask1_target_count)) mask_counts[] = {id(mask1_target_count), id(mask2_target_count)};
        int counts[4] = {0, 0, 0, 0};
        int masked[2] = {0, 0};

        for (int t = 0; t < 3; t++) {
          // The templates apply the mounting-angle correction, so x/y are
          // already in "true" forward/center coordinates.
          pos_x[t]->update();
          pos_y[t]->update();
          float x = pos_x[t]->state, y = pos_y[t]->state;
          bool valid = !(std::isnan(x) || std::isnan(y));

          // Exclusion zones take priority: a masked target counts toward no
          // tracking zone and is reported as if it were not detected at all.
          if (valid) {
            for (int e = 0; e < 2; e++) {
              if (in_poly(x, y, exclusions[e])) {
                masked[e]++;
                valid = false;
              }
            }
          }
          if (!valid) {
            pos_x[t]->publish_state(NAN);
            pos_y[t]->publish_state(NAN);
          } else {
            for (int z = 0; z < 4; z++) {
              if (in_poly(x, y, zones[z])) counts[z]++;
            }
          }

          if (detail >= 2) actives[t]->publish_state(valid);
          if (detail >= 3) {
            distances[t]->update();
            angles[t]->update();
          }
          if (detail >= 4) {
            speeds[t]->update();
            resolutions[t]->update();
          }
        }

        for (int z = 0; z < 4; z++) {
          if (detail >= 1) zone_counts[z]->publish_state(counts[z]);
          zone_presence[z]->publish_state(counts[z] > 0);
        }
        if (detail >= 1) {
          for (int e = 0; e < 2; e++) mask_counts[e]->publish_state(masked[e]);
        }
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

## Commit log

2026-09-13 feat: initial board and firmware (#1)
    [Ball Socket.stl, Base.stl, Button.stl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]
2026-09-20 fix: minor esphome config issues (#2)
    [base.yaml, ld2450.yaml]
2026-09-28 feat: add more case ventalation
    [Base.stl]

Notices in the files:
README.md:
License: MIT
